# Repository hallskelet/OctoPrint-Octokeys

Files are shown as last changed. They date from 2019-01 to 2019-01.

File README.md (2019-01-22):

# OctoPrint-Octokeys
### Плагин клавиатуры для приручения осьминога

На данный момент плагин в разработке и требует доделки до рабочего состояния.

Этот плагин является ответвлением идеи плагина: https://github.com/pkElectronics/OctoPrint-Octoremote
Также существует вариант с отдельным блоком кнопок https://github.com/eta4ever/OctoPrint-Octoremote

Аппаратная реализация плагина сделана на ардуино и полностью совместима с названными проектами.
Пульт представляет собой восемь тактовых кнопок смонтированных на макетной плате. Опрос кнопок и связь с осьминогом выполняет ардуино.
Корпус пульта выполнен в виде удиной конструкции с кожухом дисплея, для оптимизации крепления и эргономичности.

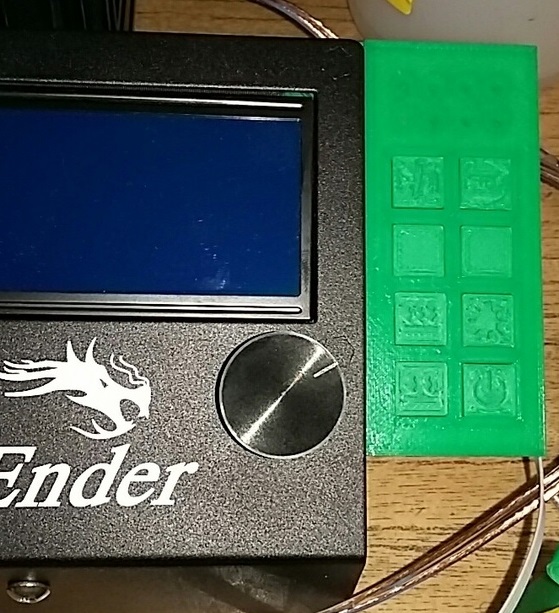
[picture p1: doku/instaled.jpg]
Корпус


Верхние 2 кномки имеют фиксированные команды: 1я - Старт последней печати/пауза/продолжение печати, в зависимости от текущего стостояния принтера. 2я - остановка печати.
Далее кнопки программируемые. На них можно натроить выполнение команды Г кода или скрипта из этих команд.

Основным отличием от аналогов является возможность назначить на кнопку изменение пина GPIO ежевики по нажатик кнопки. Этот режим можно применять напримен для управления подсветкой или включением принтера с места. Поскольку в том случае если оператор находится возле принтера ему крайне затруднительно управлять принтером через вебинтерфеес.

Расположение кнопок на клавиатуре:

| Старт/Пауза | Стоп |
|:----:|:---:|
| Настраиваемая 1 | Настраиваемая 2 |
| Настраиваемая 1 | Настраиваемая 2 |
| Настраиваемая 3 | Настраиваемая 4 |
| Настраиваемая 5 | Настраиваемая 6 |

В папках Board и case есть документация для изготовления платы и курпуса.

Вот так это получилось у меня:

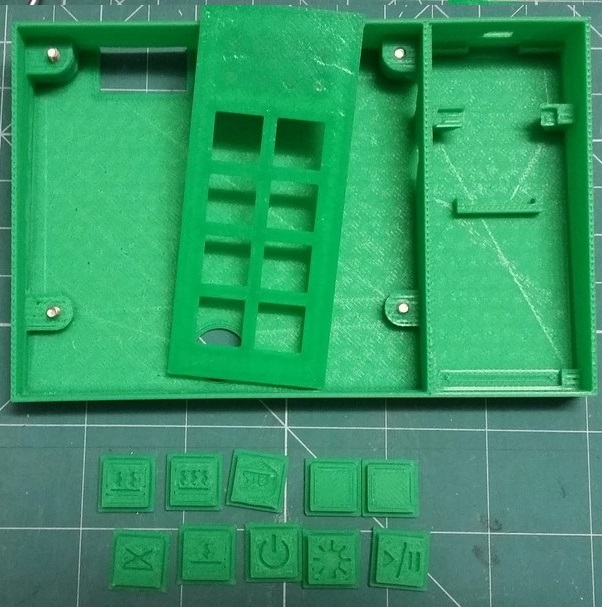
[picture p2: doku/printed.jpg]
Напечатанное


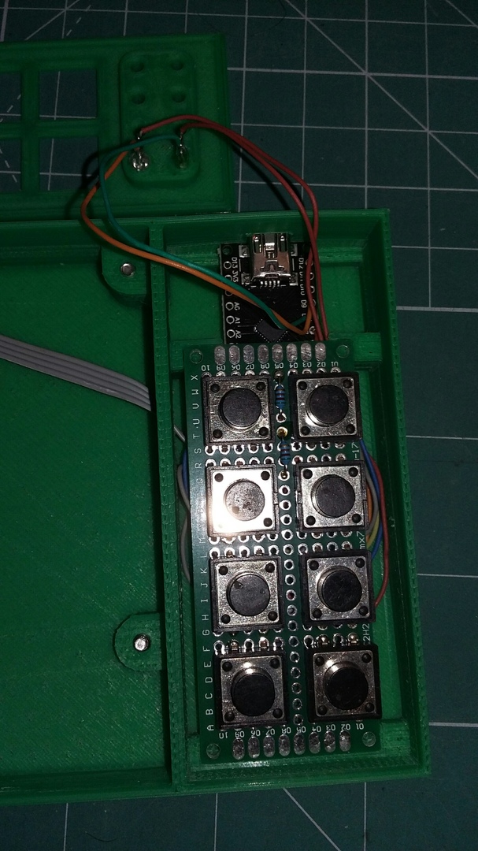
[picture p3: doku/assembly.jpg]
Сборка


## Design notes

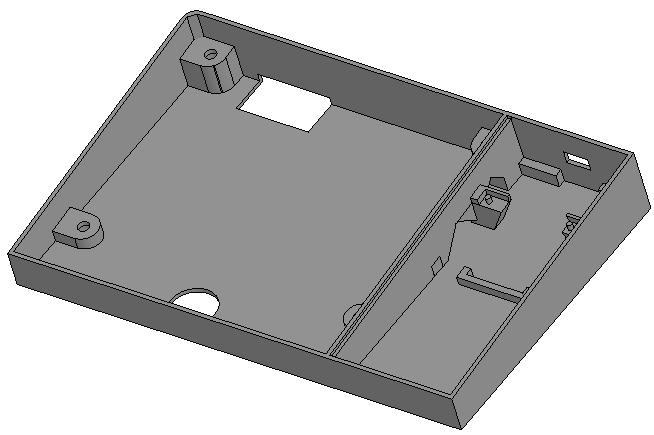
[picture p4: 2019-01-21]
CASE/src/case/case.jpg

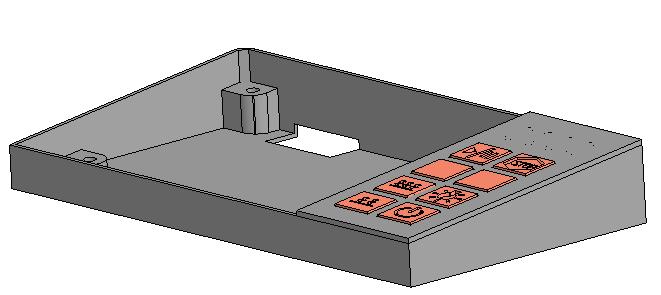
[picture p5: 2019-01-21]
CASE/src/Сборка.jpg

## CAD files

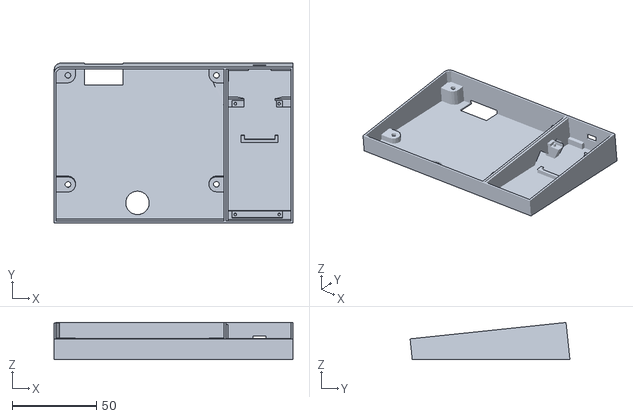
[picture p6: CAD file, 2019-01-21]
CASE/To print/case.stl
141.7 x 94.8 x 22.0

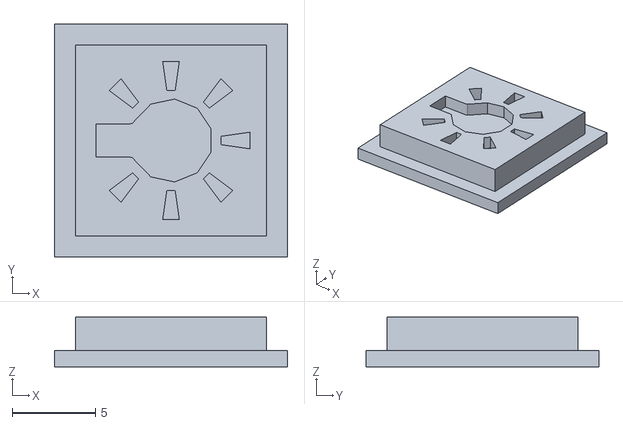
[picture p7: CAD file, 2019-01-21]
CASE/To print/button_heat_ligte.stl
14.0 x 14.0 x 3.00

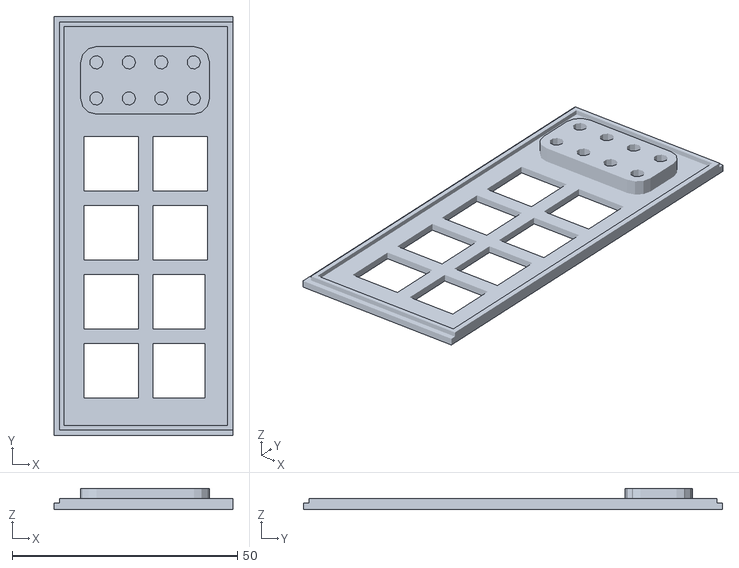
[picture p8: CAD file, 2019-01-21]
CASE/To print/top_2.stl
39.7 x 93.0 x 4.72

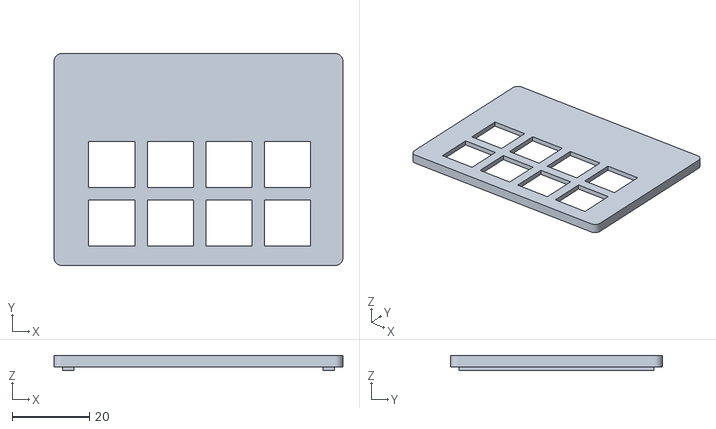
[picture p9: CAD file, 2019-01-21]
CASE/To print/top.stl
75.0 x 55.0 x 4.00

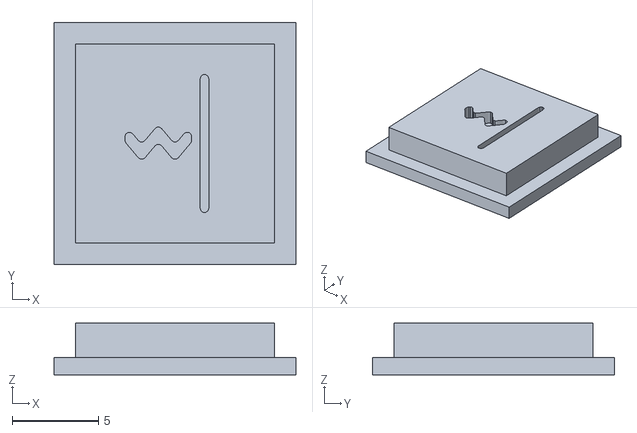
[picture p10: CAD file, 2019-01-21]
CASE/To print/button_heat_low.stl
14.0 x 14.0 x 3.00

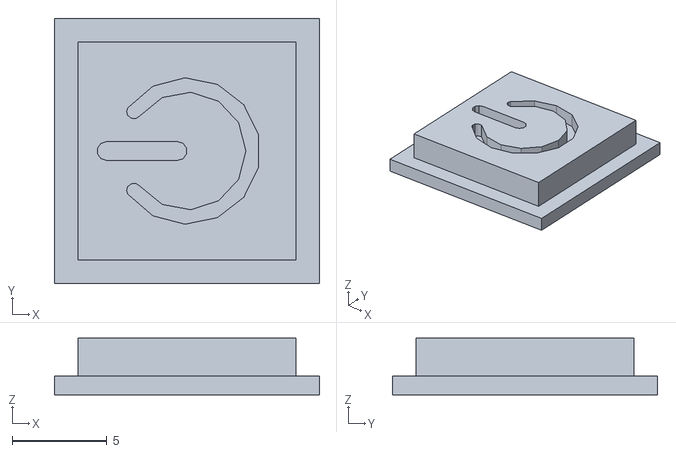
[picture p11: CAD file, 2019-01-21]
CASE/To print/button_heat_power.stl
14.0 x 14.0 x 3.00

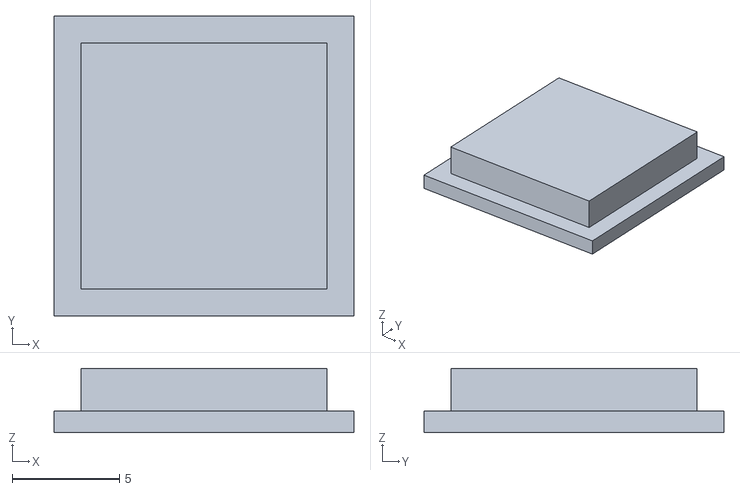
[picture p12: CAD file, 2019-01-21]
CASE/To print/button.stl
14.0 x 14.0 x 3.00

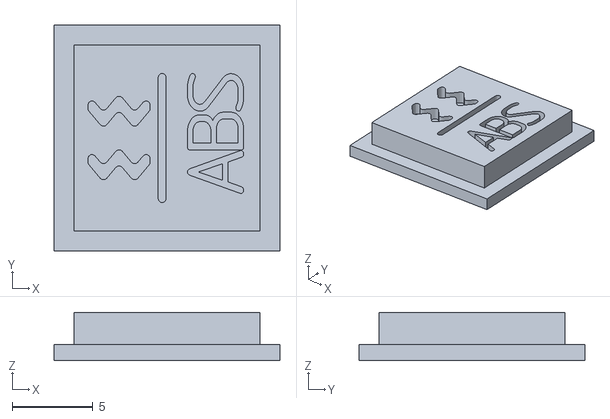
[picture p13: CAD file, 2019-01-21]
CASE/To print/button_heat_abs.stl
14.0 x 14.0 x 3.00

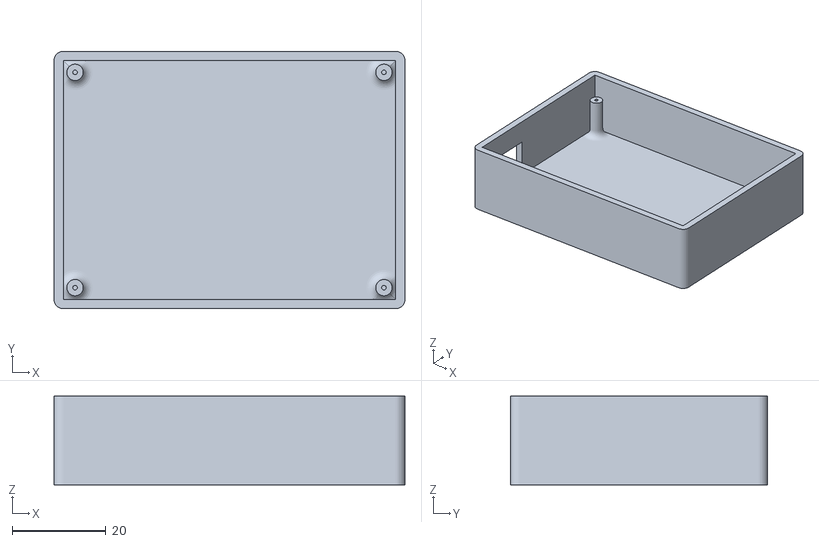
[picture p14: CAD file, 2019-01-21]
CASE/To print/back.stl
75.0 x 55.0 x 19.0

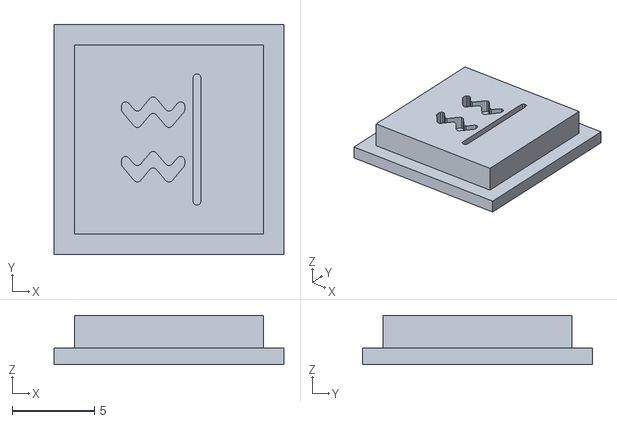
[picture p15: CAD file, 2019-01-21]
CASE/To print/button_heat.stl
14.0 x 14.0 x 3.00

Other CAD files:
CASE/To print/button_play-pause.stl
CASE/To print/button_heat_off.stl
CASE/To print/button_stop.stl
CASE/To print/button_heat_hot.stl

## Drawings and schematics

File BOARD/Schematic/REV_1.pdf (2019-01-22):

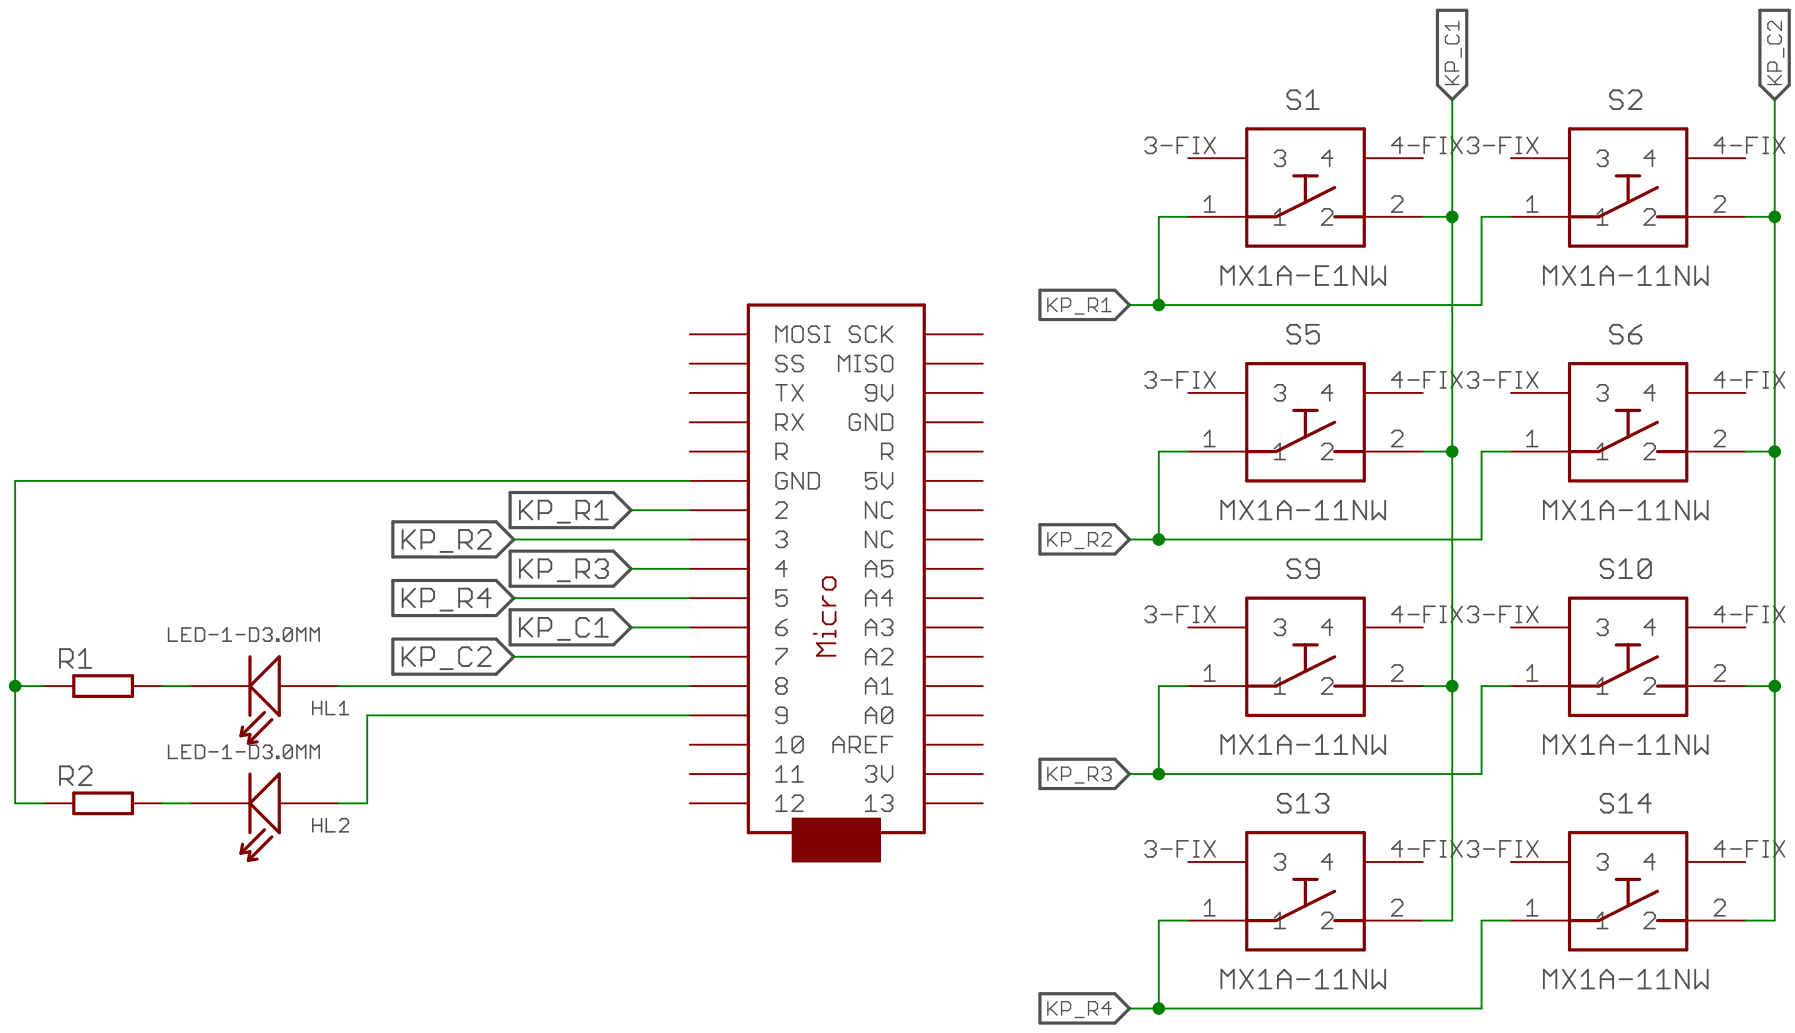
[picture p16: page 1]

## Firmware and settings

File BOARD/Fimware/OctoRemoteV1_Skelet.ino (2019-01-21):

// =============================================================================
//
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
// =============================================================================
// Requires CRC32 Library by Christopher Baker 
// Requires Keypad Library by Mark Stanley and Alexander Brevig
// Available through the Arduino Library Manager
#include <CRC32.h>
#include <Keypad.h>


// Регист не используется
//DATA PD6 -> D6
//CLOCK PB0 -> D8
//RESET PD7 -> D7

//#define SR_RESET 4
//#define SR_DATA 11
//#define SR_CLOCK 12

//Подключено только 2 светодиода можно добавить ещё много.
// Но я не знаю зачем.
#define GREEN_LED 8
#define RED_LED   9

// Псевдонимы кодов кнопок для упрощения их упихивания в массив.
// Оригинальные коды
/*
#define CHANGEMOVE 0x11
#define XPLUS 0x12
#define EPLUS 0x13
#define ZPLUS 0x14
#define YMINUS 0x21
#define HOMEXY 0x22
#define YPLUS 0x23
#define HOMEZ 0x24
#define CHANGETOOL 0x31
#define XMINUS 0x32
#define RETRACT 0x33
#define ZMINUS 0x34
#define STOP 0x41
#define PAUSE 0x42
#define PLAY 0x43
#define USER2 0x44
#define USER3 0x51
#define USER4 0x52
#define USER5 0x53
#define NOTPOPULATED 0x54
*/

// Псевдонимы кодов кнопок для упрощения их упихивания в массив.
#define PLAY_PAUSE 0x11
#define STOP       0x12
#define USER1      0x13
#define USER2      0x14
#define HEAT1      0x21
#define HEAT2      0x22
#define LITE       0x23
#define POWER      0x24


const byte ROWS = 4; // в отличии от оригинала у нас меньше строк (five rows)
const byte COLS = 2; // и сильно меньше колонок (four columns)
//define the cymbols on the buttons of the keypads
// Клавиатура сильно сморщилась, так и то 2 кнопки неизвесно под что
char hexaKeys[ROWS][COLS] = {
  {PLAY_PAUSE,STOP},
  {USER1,USER2},
  {HEAT2,LITE},
  {HEAT1,POWER}
};
/*      
 *       
 *       ----
 *      |R5C2|
 *  ----------------
 *  |R4C4|R5C3|R5C1|
 *  ----------------
 *  |R3C4|R4C2|R5C1|
 *  ----------------
 *  |R2C4|R3C3|R4C1|
 *  ----------------
 *  |R2C3|R3C2|R3C1|
 *  ----------------
 *  |R1C4|R2C2|R2C1|
 *  ----------------
 *  |R1C3|R1C2|R1C1|
 *  ----------------
 * 
 */

byte rowPins[ROWS] = {2, 3, 4, 5}; //connect to the row pinouts of the keypad
byte colPins[COLS] = {6, 7}; //connect to the column pinouts of the keypad

#define TRANSMISSION_HEADER 0x80
#define COMMAND_KEYPRESSED 0x10
#define COMMAND_KEYRELEASED 0x11
#define COMMAND_KEYHOLD 0x12
#define COMMAND_SETLED 0x20

#define COMMAND_ACK 0x01
#define COMMAND_NACK 0x02


void sendKeyToHost(char key,char cmd);
void resendLastCommand(void);
void handleSerial(void);

//initialize an instance of class NewKeypad
Keypad customKeypad = Keypad( makeKeymap(hexaKeys), rowPins, colPins, ROWS, COLS); 
CRC32 crc;

char ackPending = false;
long lastSendTime = 0;
char lastSendKey = 0;
char lastSendCMD = 0;
uint8_t retryCounter = 0;

/* // Сдвигового регистра у нас нет и так много свободных портов
void writeByteToSR(byte data){
  for(int i = 0 ; i < 8 ; i++){
    PORTD &= ~(1<<PD6);
    
    if( (data) & (1<<i) ){
      PORTB |= (1 << PB7);
    }else{
      PORTB &= ~(1<<PB7);
    }
    
    PORTD |= (1<<PD6);
    
   }
}
*/

void setup(){
  Serial.begin(115200);
  
  
  
  customKeypad.addEventListener(keypadEvent);

// Инициализация пинов светодиодов
pinMode(GREEN_LED,OUTPUT);
pinMode(RED_LED,OUTPUT);
digitalWrite(GREEN_LED,HIGH);
digitalWrite(RED_LED,HIGH);
delay(100);

/*  pinMode(SR_RESET,OUTPUT);
  pinMode(SR_DATA,OUTPUT);
  pinMode(SR_CLOCK,OUTPUT);

  digitalWrite(SR_RESET,LOW);
  
  digitalWrite(SR_DATA,LOW);
  digitalWrite(SR_CLOCK,LOW);
  digitalWrite(SR_RESET,HIGH);
// тест светодиодов
for(int i = 0 ; i < 8 ; i++){
    writeByteToSR(1<<i);
    delay(100);
  }*/
  setLeds(0); 
}



void keypadEvent(KeypadEvent key){
    switch (customKeypad.getState()){
    case PRESSED:
        sendKeyToHost(key,COMMAND_KEYPRESSED);
        break;

    case RELEASED:
        sendKeyToHost(key,COMMAND_KEYRELEASED);
        break;

    case HOLD:
        sendKeyToHost(key,COMMAND_KEYHOLD);
        break;
    }
}

long lastcall = 0L;
unsigned char ledIndex = 0;

unsigned char telegramLength = 0;
unsigned char telegramCommand = 0;
unsigned char payload[256];
unsigned char payloadIndex = 0;
unsigned char parsingState = 0;
uint32_t telegramCRC = 0;

  
void loop(){
  char key = customKeypad.getKey();
  if(ackPending && (millis()- lastSendTime > 2000) && retryCounter < 3){
    resendLastCommand();
    retryCounter++;
  }
  handleSerial();
}

int row1 = 0;
int row2 = 0;

void setLeds(byte b){

switch(b){
    case 0:
      digitalWrite(GREEN_LED,LOW);
      digitalWrite(RED_LED,LOW);
      break;
    case 1:
      digitalWrite(GREEN_LED,HIGH);
      break;
    case 2:
      digitalWrite(GREEN_LED,LOW);
      break;
    case 3:
      digitalWrite(RED_LED,HIGH);
      break;
    case 4:
      digitalWrite(RED_LED,LOW);
      break;
    default:
      digitalWrite(GREEN_LED,LOW);
      digitalWrite(RED_LED,LOW);
      break;
}
//  byte ledOut = 0;
/*
  switch(b){
    case 0:
      row1 = 1<<4;
      break;
    case 1:
      row1 = 1<<6;
      break;
    case 2:
      row1 = 1<<0;
      break;
    case 3:
      row1 = 1<<2;
      break;
    case 4:
    row2 = 1<<5;
    break;
    case 5:
    row2 = 1<<7;
    break;
    case 6:
    row2 = 1<<1;
    break;
    case 7:
    row2 = 1<<3;
    break;
    default:
    break;
  }*/
//  writeByteToSR(row1|row2);
  
}

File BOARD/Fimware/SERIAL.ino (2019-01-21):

void sendKeyToHost(char key,char cmd){
  crc.reset();
  crc.update(TRANSMISSION_HEADER);
  crc.update(8);
  crc.update(cmd);
  crc.update(key);
  uint32_t checksum = crc.finalize();
  Serial.write(TRANSMISSION_HEADER); //STX
  Serial.write(8); //LENGTH
  Serial.write(cmd); //Command (Key Pressed)
  Serial.write(key);
  for(int i = 0; i < 4 ; i++){
    Serial.write( (checksum>>(8*i) & 0xFF));
  }
  ackPending = true;
  lastSendKey = key;
  lastSendCMD = cmd;
  lastSendTime = millis();
  retryCounter= 0;
}

void resendLastCommand(){
  sendKeyToHost(lastSendKey,lastSendCMD);
}


void sendSingleCMD(char command){
  crc.reset();
  crc.update(TRANSMISSION_HEADER);
  crc.update(7);
  crc.update(command);
  uint32_t checksum = crc.finalize();
  Serial.write(TRANSMISSION_HEADER); //STX
  Serial.write(7); //LENGTH
  Serial.write(command); //Command (Key Pressed)
  for(int i = 0; i < 4 ; i++){
    Serial.write( ((checksum>>(8*i)) & 0xFF));
  }
}
void sendACK(){
 sendSingleCMD(COMMAND_ACK); 
}
void sendNACK(){
  sendSingleCMD(COMMAND_NACK); 
}
void handleSerial(){
  
  if(Serial.available() > 0){
    unsigned char readbyte = Serial.read();
    unsigned long b = readbyte;
    
    switch(parsingState){
      case 0: //STX
        if(readbyte == 0x80) parsingState++;
        payloadIndex = 0;
        telegramLength = 0;
        telegramCommand = 0;
        telegramCRC = 0;
        break;
      case 1: //LENGTH
        telegramLength = readbyte;
        //payloadIndex = telegramLength -7;
        parsingState++;
        break;
      case 2: //COMMAND
        telegramCommand = readbyte;
        parsingState++;
        if(telegramLength == 7)parsingState++; //telegram ohne payload 
        break;
      case 3: //payload
        payload[payloadIndex] = readbyte;
        
        payloadIndex++;
        if( telegramLength ==  (payloadIndex + 7)){
          parsingState++;
        }
        break;

       case 4: //CRC
       case 5:
       case 6:
        telegramCRC |= b << (8*(parsingState-4));
        parsingState++;
        break;
       case 7:
        
        telegramCRC |= b << (8*(parsingState-4));
        crc.reset();
        crc.update(0x80);
        
        crc.update(telegramLength);
        
        crc.update(telegramCommand);
        
        for(int i = 0; i < payloadIndex; i++){
          crc.update(payload[i]);
          
        }
        parsingState = 0;
        if(crc.finalize() == telegramCRC){
          switch(telegramCommand){
            case COMMAND_NACK:
              resendLastCommand();
            break;

            case COMMAND_ACK:
              ackPending = false;
            break;

            case COMMAND_SETLED:
              ackPending=false;
              if(telegramLength == 8){
                sendACK();
              setLeds(payload[0]);  
              }else{
                sendNACK();
              }
              
            break;
          }
          
        }else{
          sendNACK();
        }
       break;
    }
      
  }
}

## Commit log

2019-01-29 Обновлён адрес плагина исправлена ошибка в имени плагина
2019-01-29 обновление

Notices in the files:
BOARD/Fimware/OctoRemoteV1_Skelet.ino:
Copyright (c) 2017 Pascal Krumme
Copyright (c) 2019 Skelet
